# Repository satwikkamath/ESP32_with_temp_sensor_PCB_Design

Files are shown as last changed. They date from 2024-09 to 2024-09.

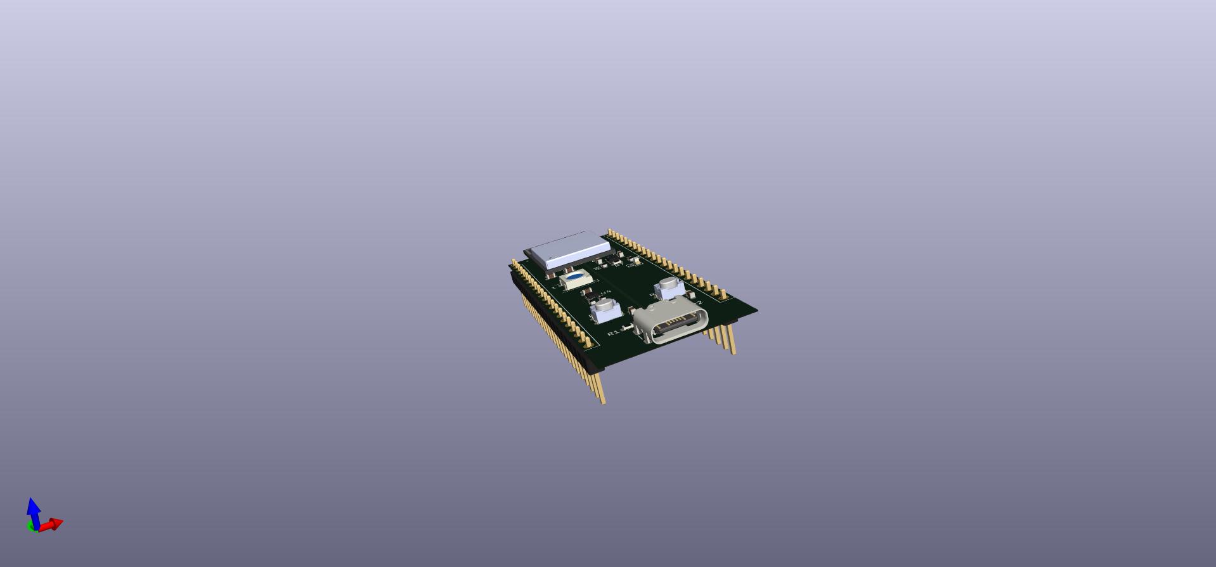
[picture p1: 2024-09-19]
3D_view2.jpg

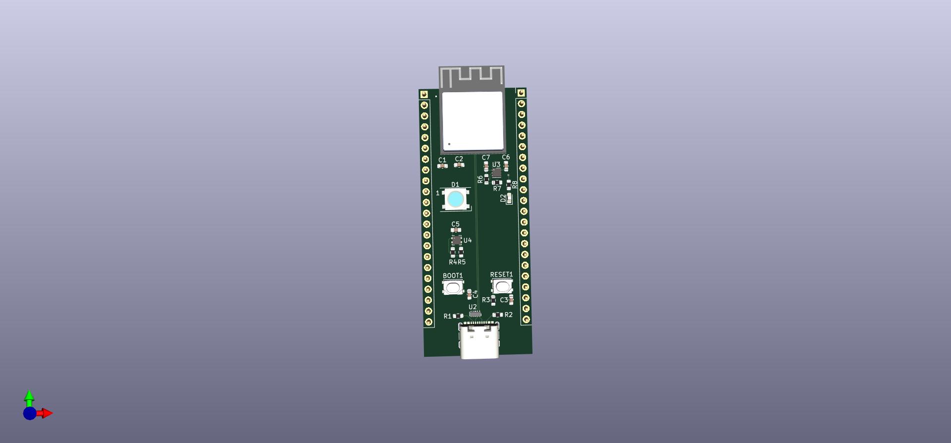
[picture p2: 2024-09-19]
3D_view1.jpg

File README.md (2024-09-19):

# ESP32-S3 PCB Design with Temperature Sensor and RGB LED

## Overview

This project focuses on designing a custom PCB using the **ESP32-S3-MINI-1-N8** microcontroller. The PCB integrates an **ENS210** temperature and humidity sensor, a **WS2812B RGB LED** for visual feedback, and a power regulation system using the **TLV75801 LDO** voltage regulator. The design also includes **TVS protection diodes** for USB input safety.

The PCB was designed using **KiCad** and is tailored for applications that require environmental sensing and LED indication, powered through USB with proper surge protection.

## Features

- **ESP32-S3-MINI-1-N8**: A powerful microcontroller for managing sensors, RGB LED, and communication.
- **ENS210 Temperature & Humidity Sensor**: Provides accurate temperature and humidity readings.
- **WS2812B RGB LED**: Addressable LED for visual indication based on temperature readings.
- **TLV75801 LDO Regulator**: Provides a stable 3.3V output from the USB 5V input.
- **USB Surge Protection**: Includes **D3V3XA4B10LP TVS diodes** for protecting the USB input from overvoltage or surge.

## Schematic Design

The schematic was created using **KiCad** and includes the following blocks:

1. **ESP32-S3 Microcontroller**: 
   - Handles the processing and communication.
   - I²C interface to the ENS210 sensor.
   - GPIO control for the WS2812B RGB LED.

2. **ENS210 Temperature & Humidity Sensor**:
   - Connected via the I²C bus.
   - Powered by 3.3V from the regulator.

3. **WS2812B RGB LED**:
   - Data pin connected to GPIO48 of the ESP32.
   - Powered by the 3.3V rail.

4. **TLV75801 LDO**:
   - Regulates 5V USB input to a stable 3.3V output for all components.

5. **TVS Diodes**:
   - Protect the USB power input from surges.

## PCB Layout

The PCB layout includes:

- **Compact design**: Minimizes the space required while keeping all components well-organized.
- **Optimized power and ground planes**: Ensures stable operation and reduces noise.
- **Via stitching**: Improves ground plane integrity.
- **Thermal relief pads**: Used for better heat dissipation where needed.
- **USB Input Protection**: TVS diodes are placed near the USB input to provide surge protection.

# STATUS: ONGOING

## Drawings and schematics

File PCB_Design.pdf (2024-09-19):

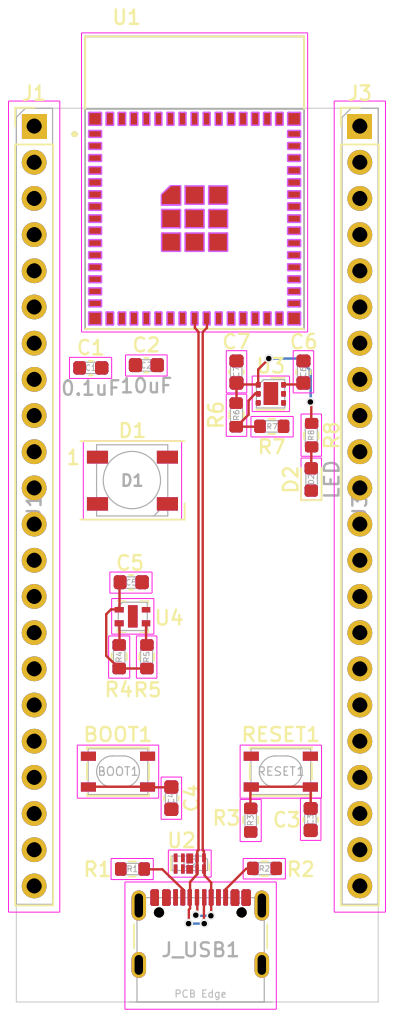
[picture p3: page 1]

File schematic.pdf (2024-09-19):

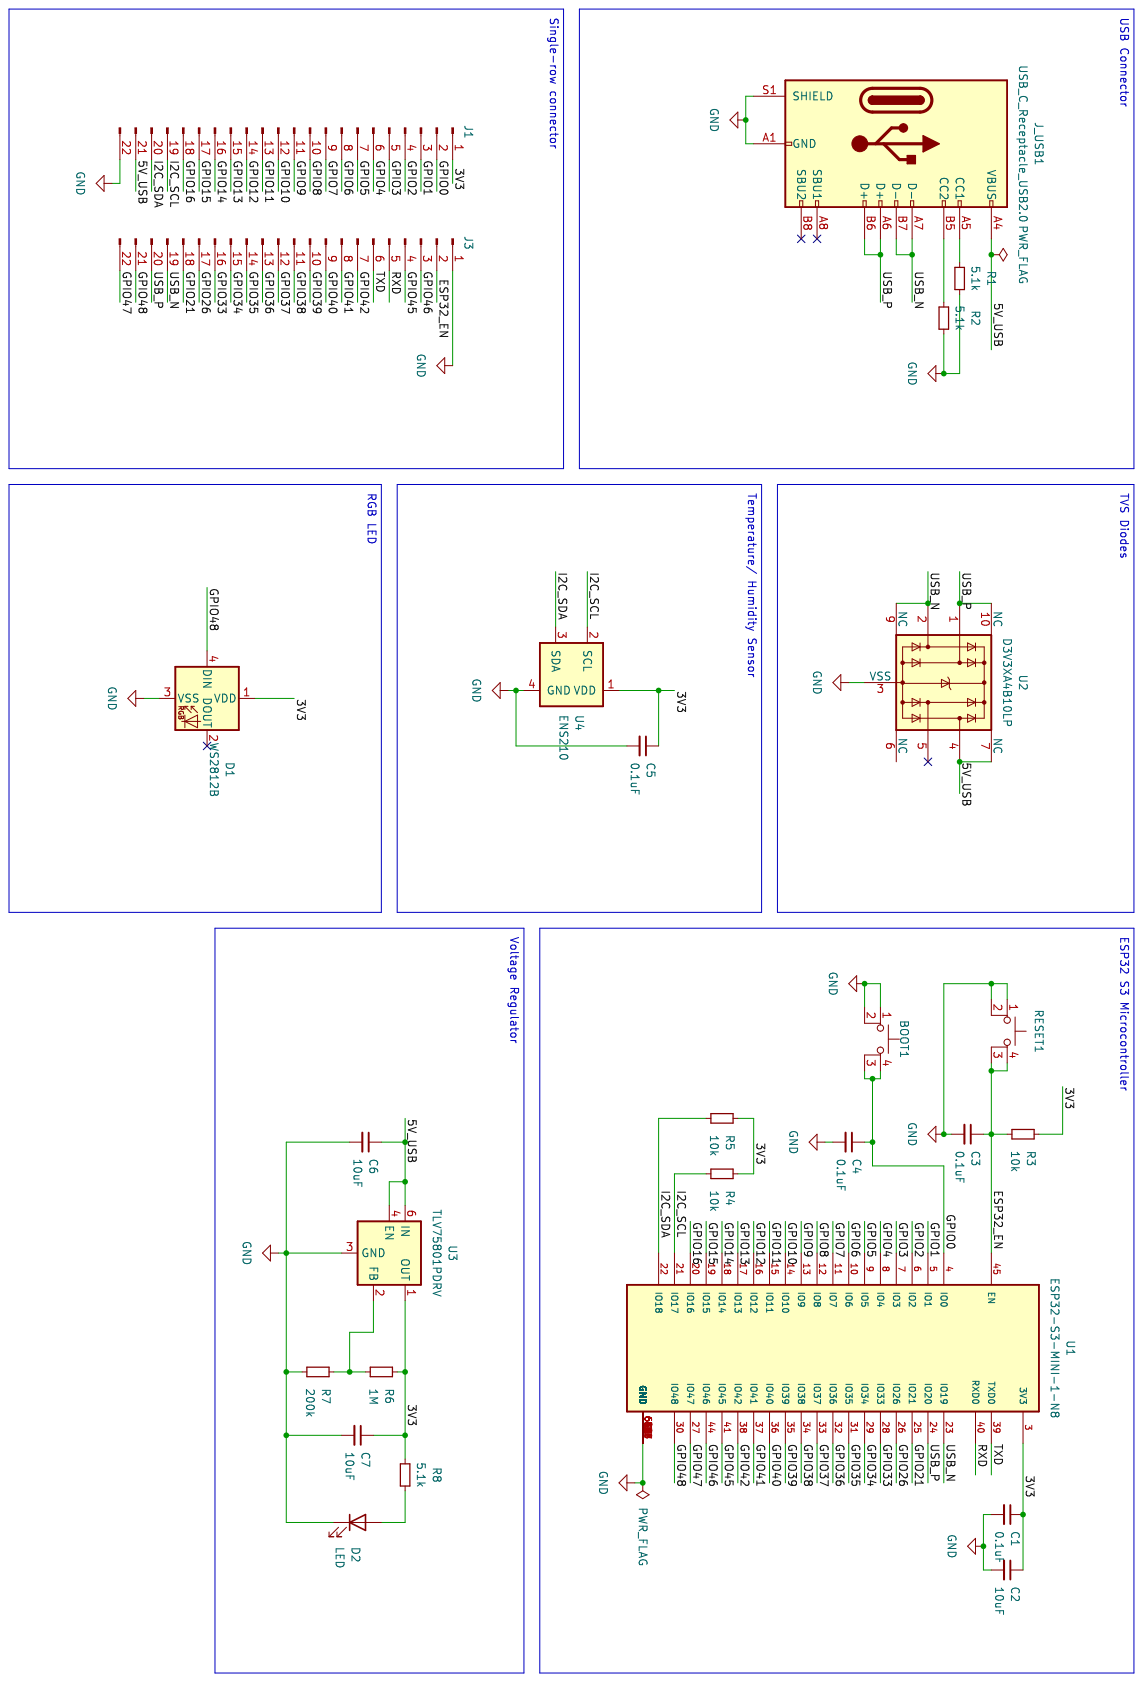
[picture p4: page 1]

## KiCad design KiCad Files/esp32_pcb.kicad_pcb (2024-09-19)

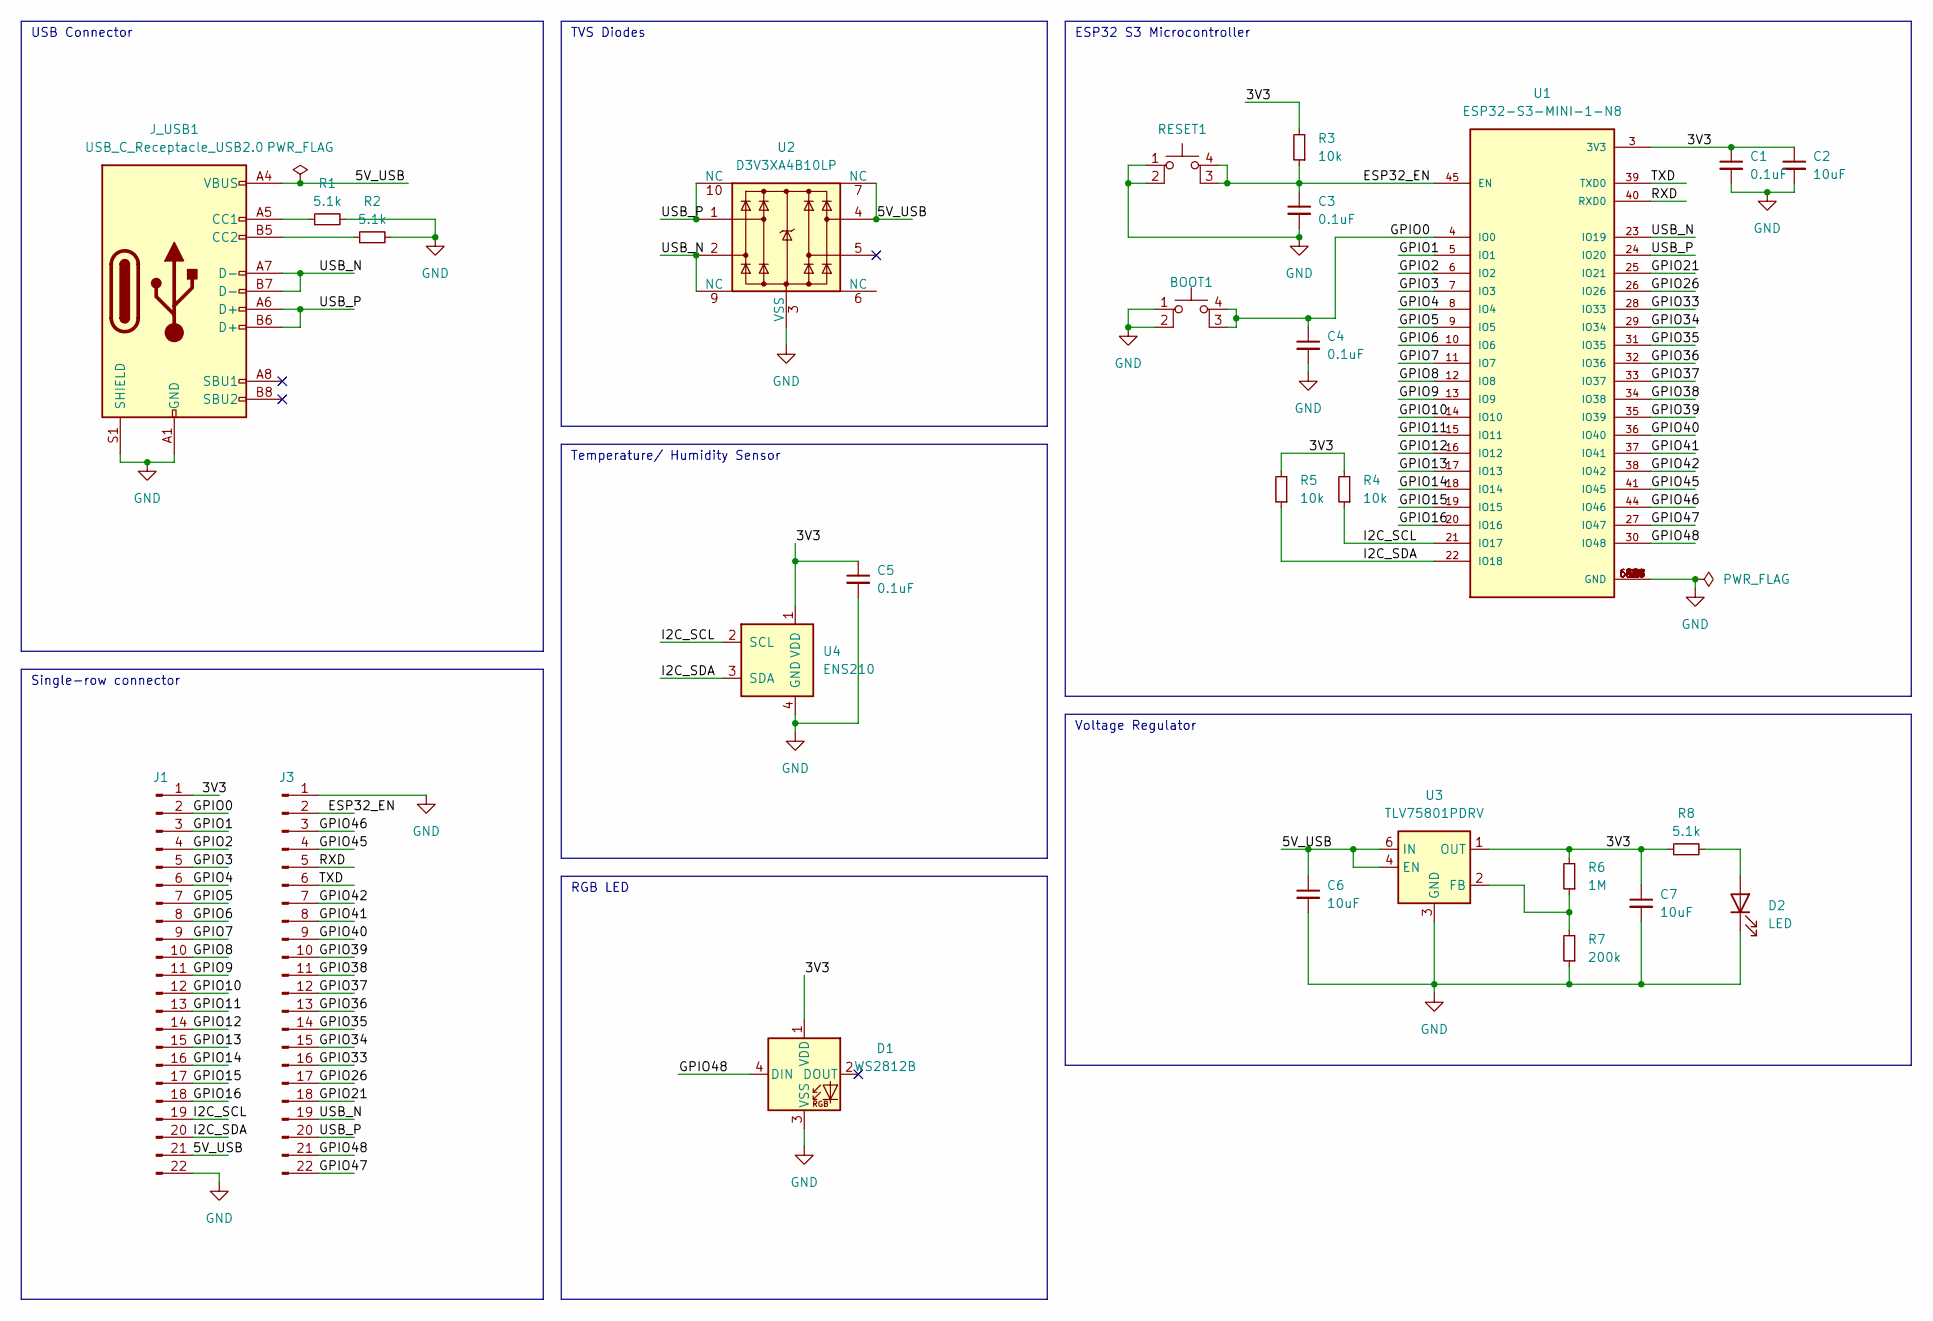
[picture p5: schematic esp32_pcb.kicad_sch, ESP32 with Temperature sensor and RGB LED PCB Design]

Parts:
BOOT1: SW_SPST_PTS810
C1, C3, C4, C5: 0.1uF; C_0603_1608Metric
C2, C6, C7: 10uF; C_0603_1608Metric
D1: WS2812B; LED_WS2812B_PLCC4_5.0x5.0mm_P3.2mm
D2: LED; LED_0603_1608Metric
J1: PinHeader_1x22_P2.54mm_Vertical
J3: Conn_01x22_Pin; PinHeader_1x22_P2.54mm_Vertical
J_USB1: USB_C_Receptacle_USB2.0; USB_C_Receptacle_GCT_USB4105-xx-A_16P_TopMnt_Horizontal
R1, R2, R8: 5.1k; R_0603_1608Metric
R3, R4, R5: 10k; R_0603_1608Metric
R6: 1M; R_0603_1608Metric
R7: 200k; R_0603_1608Metric
RESET1: SW_SPST_PTS810
U1: ESP32-S3-MINI-1-N8; XCVR_ESP32-S3-MINI-1-N8; PARTREV v0.6
U2: D3V3XA4B10LP; Diodes_UDFN-10_1.0x2.5mm_P0.5mm
U3: TLV75801PDRV; WSON-6-1EP_2x2mm_P0.65mm_EP1x1.6mm
U4: ENS210; AMS_QFN-4-1EP_2x2mm_P0.95mm_EP0.7x1.6mm

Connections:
/3V3: C1.1, C2.1, C5.1, C7.1, D1.1 (VDD), J1.1, R3.2, R4.2, R5.2, R6.2, R8.1, U1.3 (3V3), U3.1 (OUT), U4.1 (VDD)
/5V_USB: C6.1, J1.21, J_USB1.A4 (VBUS), J_USB1.A9 (VBUS), J_USB1.B4 (VBUS), J_USB1.B9 (VBUS), U2.4, U2.7 (NC), U3.4 (EN), U3.6 (IN)
/ESP32_EN: C3.1, J3.2, R3.1, RESET1.3 (K), RESET1.4 (A), U1.45 (EN)
/GPIO0: BOOT1.3 (K), BOOT1.4 (A), C4.1, J1.2, U1.4 (IO0)
/GPIO1: J1.3, U1.5 (IO1)
/GPIO2: J1.4, U1.6 (IO2)
/GPIO3: J1.5, U1.7 (IO3)
/GPIO4: J1.6, U1.8 (IO4)
/GPIO5: J1.7, U1.9 (IO5)
/GPIO6: J1.8, U1.10 (IO6)
/GPIO7: J1.9, U1.11 (IO7)
/GPIO8: J1.10, U1.12 (IO8)
/GPIO9: J1.11, U1.13 (IO9)
/GPIO10: J1.12, U1.14 (IO10)
/GPIO11: J1.13, U1.15 (IO11)
/GPIO12: J1.14, U1.16 (IO12)
/GPIO13: J1.15, U1.17 (IO13)
/GPIO14: J1.16, U1.18 (IO14)
/GPIO15: J1.17, U1.19 (IO15)
/GPIO16: J1.18, U1.20 (IO16)
/GPIO21: J3.18, U1.25 (IO21)
/GPIO26: J3.17, U1.26 (IO26)
/GPIO33: J3.16, U1.28 (IO33)
/GPIO34: J3.15, U1.29 (IO34)
/GPIO35: J3.14, U1.31 (IO35)
/GPIO36: J3.13, U1.32 (IO36)
/GPIO37: J3.12, U1.33 (IO37)
/GPIO38: J3.11, U1.34 (IO38)
/GPIO39: J3.10, U1.35 (IO39)
/GPIO40: J3.9, U1.36 (IO40)
/GPIO41: J3.8, U1.37 (IO41)
/GPIO42: J3.7, U1.38 (IO42)
/GPIO45: J3.4, U1.41 (IO45)
/GPIO46: J3.3, U1.44 (IO46)
/GPIO47: J3.22, U1.27 (IO47)
/GPIO48: D1.4 (DIN), J3.21, U1.30 (IO48)
/I2C_SCL: J1.19, R4.1, U1.21 (IO17), U4.2 (SCL)
/I2C_SDA: J1.20, R5.1, U1.22 (IO18), U4.3 (SDA)
/RXD: J3.5, U1.40 (RXD0)
/TXD: J3.6, U1.39 (TXD0)
/USB_N: J3.19, J_USB1.A7 (D-), J_USB1.B7 (D-), U1.23 (IO19), U2.2, U2.9 (NC)
/USB_P: J3.20, J_USB1.A6 (D+), J_USB1.B6 (D+), U1.24 (IO20), U2.1, U2.10 (NC)
GND: BOOT1.1, BOOT1.2, C1.2, C2.2, C3.2, C4.2, C5.2, C6.2, C7.2, D1.3 (VSS), D2.1 (K), J1.22, J3.1, J_USB1.A1 (GND), J_USB1.A12 (GND), J_USB1.B1 (GND), J_USB1.B12 (GND), J_USB1.S1 (SHIELD), R1.2, R2.2, R7.1, RESET1.1, RESET1.2, U1.1 (GND), U1.2 (GND), U1.42 (GND), U1.43 (GND), U1.46 (GND), U1.47 (GND), U1.48 (GND), U1.49 (GND), U1.50 (GND), U1.51 (GND), U1.52 (GND), U1.53 (GND), U1.54 (GND), U1.55 (GND), U1.56 (GND), U1.57 (GND), U1.58 (GND), U1.59 (GND), U1.60 (GND), U1.61 (GND), U1.61_1 (GND), U1.61_2 (GND), U1.61_3 (GND), U1.61_4 (GND), U1.61_5 (GND), U1.61_6 (GND), U1.61_7 (GND), U1.61_8 (GND), U1.62 (GND), U1.63 (GND), U1.64 (GND), U1.65 (GND), U2.3 (VSS), U2.8 (VSS), U3.3 (GND), U3.7 (GND), U4.4 (GND), U4.5 (GND)
unnamed: D2.2 (A), R8.2
unnamed: J_USB1.A5 (CC1), R1.1
unnamed: J_USB1.B5 (CC2), R2.1
unnamed: R6.1, R7.2, U3.2 (FB)

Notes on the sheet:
Temperature/ Humidity Sensor
USB Connector
RGB LED
ESP32 S3 Microcontroller
TVS Diodes
Single-row connector
Voltage Regulator

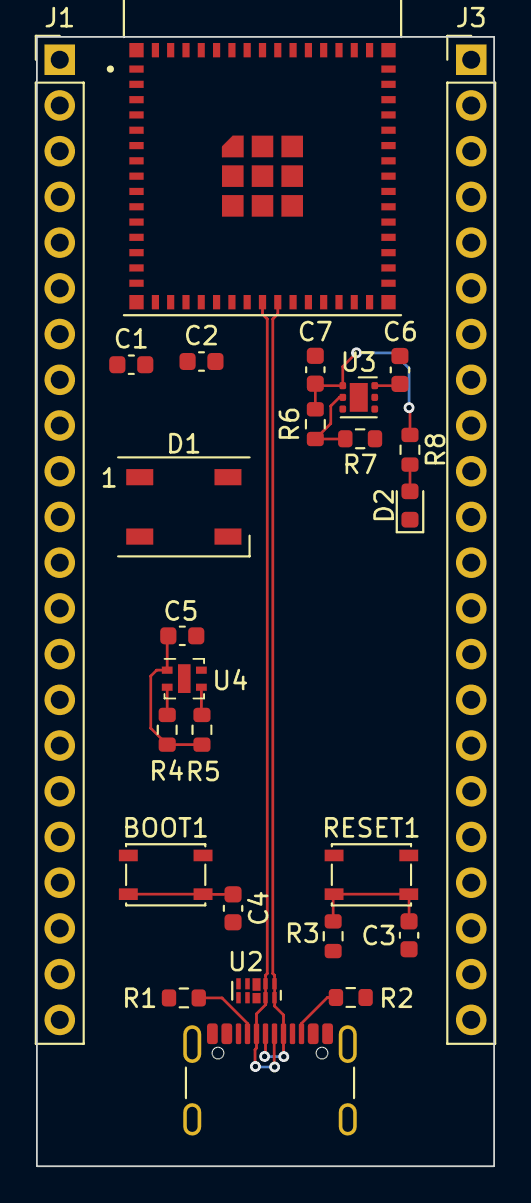
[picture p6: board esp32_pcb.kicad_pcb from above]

Board: 4 copper layers, 25.4 x 62.7 mm, 26 parts (0 on the bottom side), 47 nets.
